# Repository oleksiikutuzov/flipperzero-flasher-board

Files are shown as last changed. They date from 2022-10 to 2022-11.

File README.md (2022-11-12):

# flipperzero-flasher-board

Since version 0.70.1 you can set RTS/DTR pins to pins 16/15 and use only one row of pins for this flasher board.

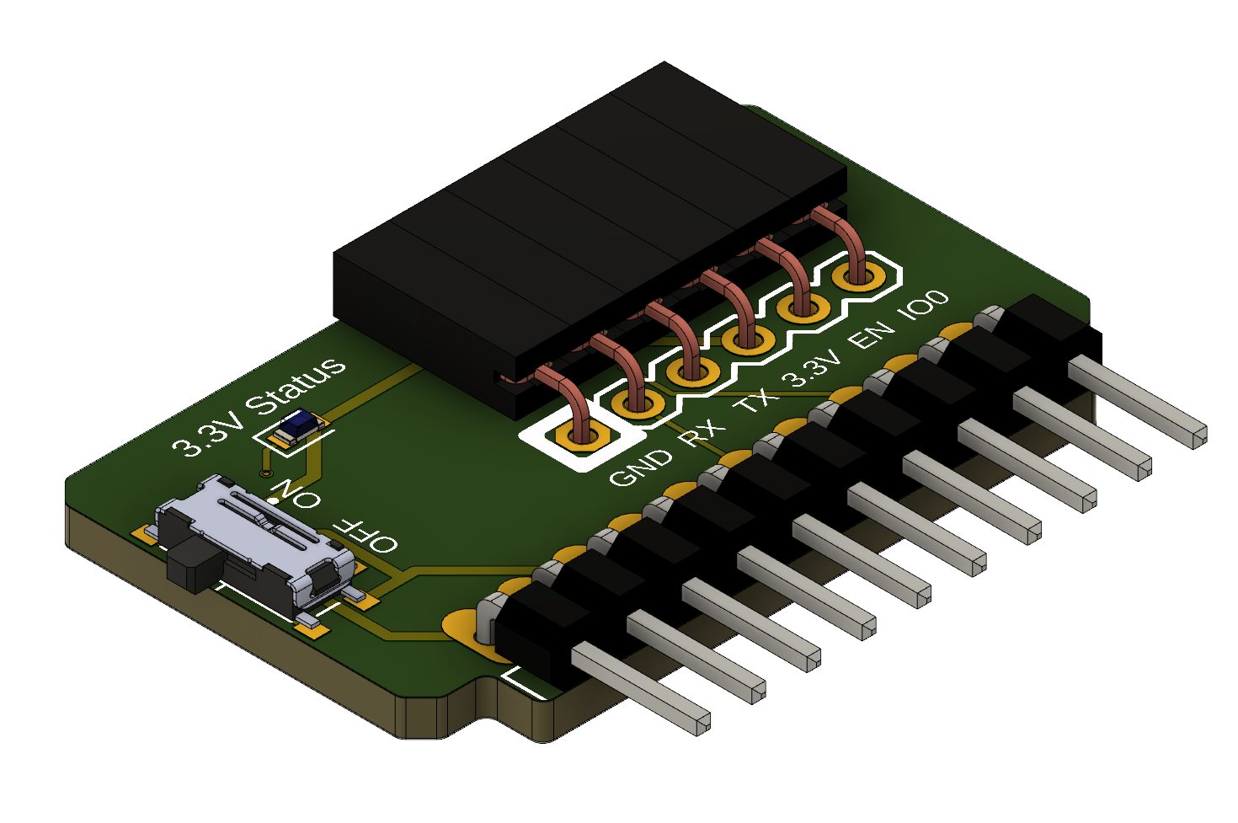
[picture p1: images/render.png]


I made this simple board to flash my ESP32 projects. It uses the [ESPFlash](https://github.com/SuperHouse/ESPFlash) pinout. Flasher has a switch to toggle 3.3V from Flipper Zero if you need to power the device you are flashing from an external power source. Recommended PCB thickness is 1.0 - 1.2 mm.

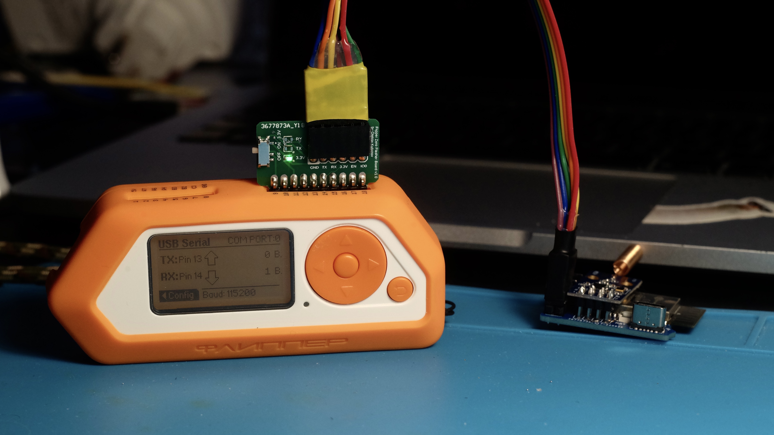
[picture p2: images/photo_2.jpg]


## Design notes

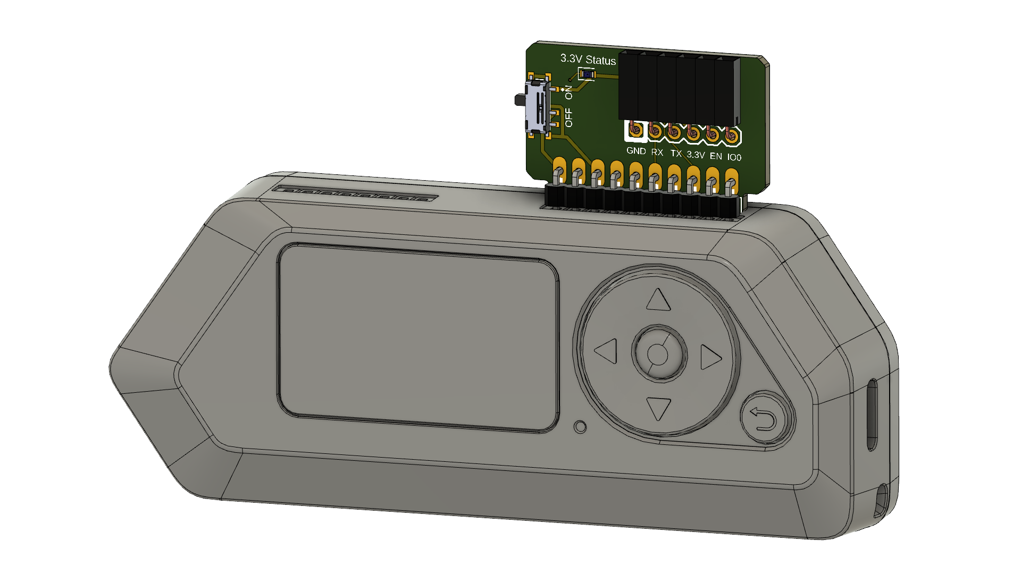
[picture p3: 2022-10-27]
images/render-flipper.png

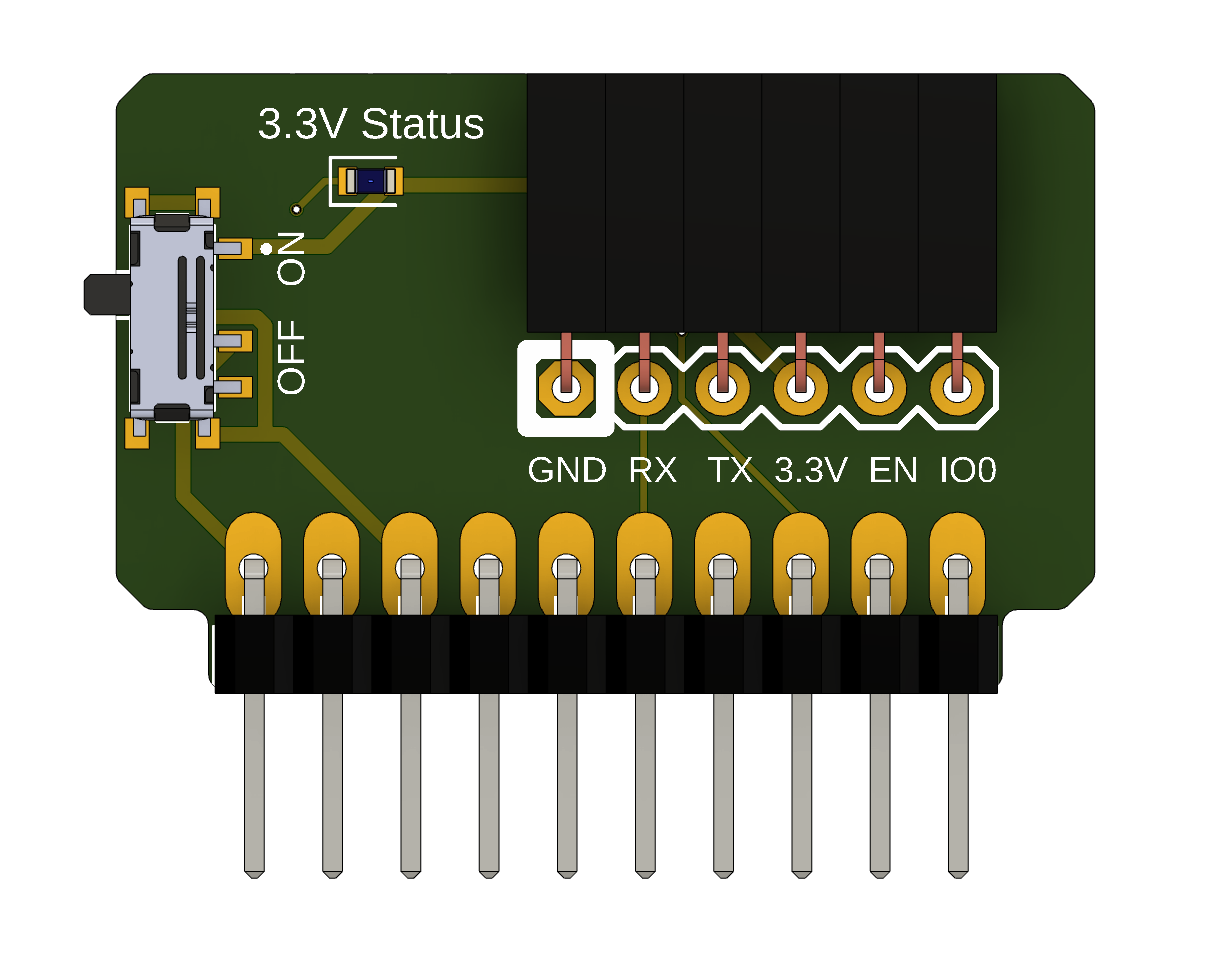
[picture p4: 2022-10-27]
images/TOP v1.1.png

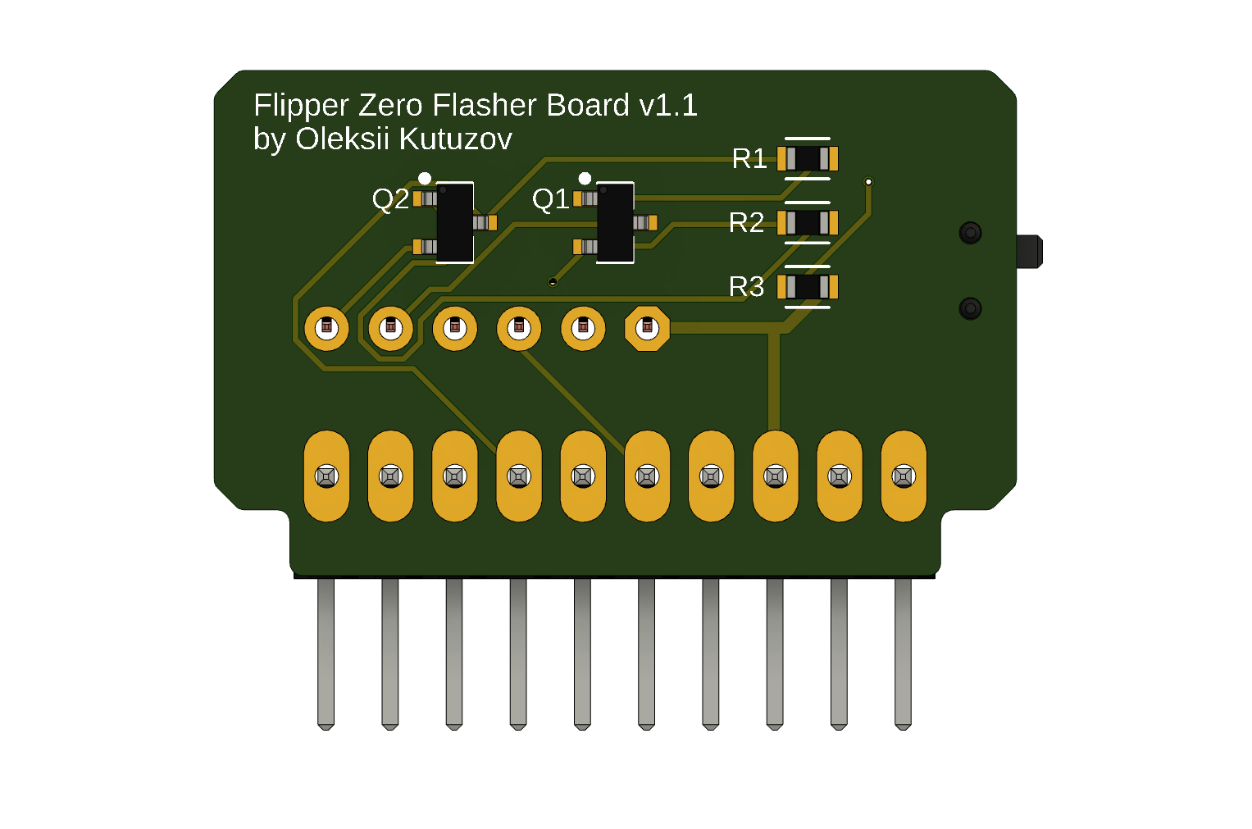
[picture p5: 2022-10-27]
images/BOTTOM v1.1.png

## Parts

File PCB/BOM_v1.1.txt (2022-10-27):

Partlist exported from /var/folders/tq/b2m_bkf11ld61j4hqq2g93cr0000gn/T/Neutron/ElectronFileOutput/14894/sch-362ab598-894d-49ed-90d1-658ffdb2f589/Schematic v7.sch at 27.10.22 18:26

Part Value                   Device                   Package             Description                                              
D1   LED_GREEN               CHIP-FLAT-B_0603-0.55MM  LEDC1608X55N_FLAT-B                                                          
ESPF ESPFLASH-1X6-2.54-PLAIN ESPFLASH-1X6-2.54-PLAIN  1X6-2.54-PLAIN      ESPFlash                                                 
JP1  PINHD-1X10/90           PINHD-1X10/90            1X10/90             PIN HEADER                                               
Q1   NPN                     NPN_SOT23-BEC            SOT95P237X112-3N    NPN - Generic                                            
Q2   NPN                     NPN_SOT23-BEC            SOT95P237X112-3N    NPN - Generic                                            
R1   12K                     R_CHIP-0603(1608-METRIC) RESC1608X60         Resistor Fixed - Generic                                 
R2   12K                     R_CHIP-0603(1608-METRIC) RESC1608X60         Resistor Fixed - Generic                                 
R3   4.7K                    R_CHIP-0603(1608-METRIC) RESC1608X60         Resistor Fixed - Generic                                 
SW1  MLL1200S                MLL1200S                 SW_MLL1200S         Switch Slide SPDT Side Slide 0.3A 4VDC Gull Wing SMD Box 
                                                                          https://a.aliexpress.com/_EyNVWSJ

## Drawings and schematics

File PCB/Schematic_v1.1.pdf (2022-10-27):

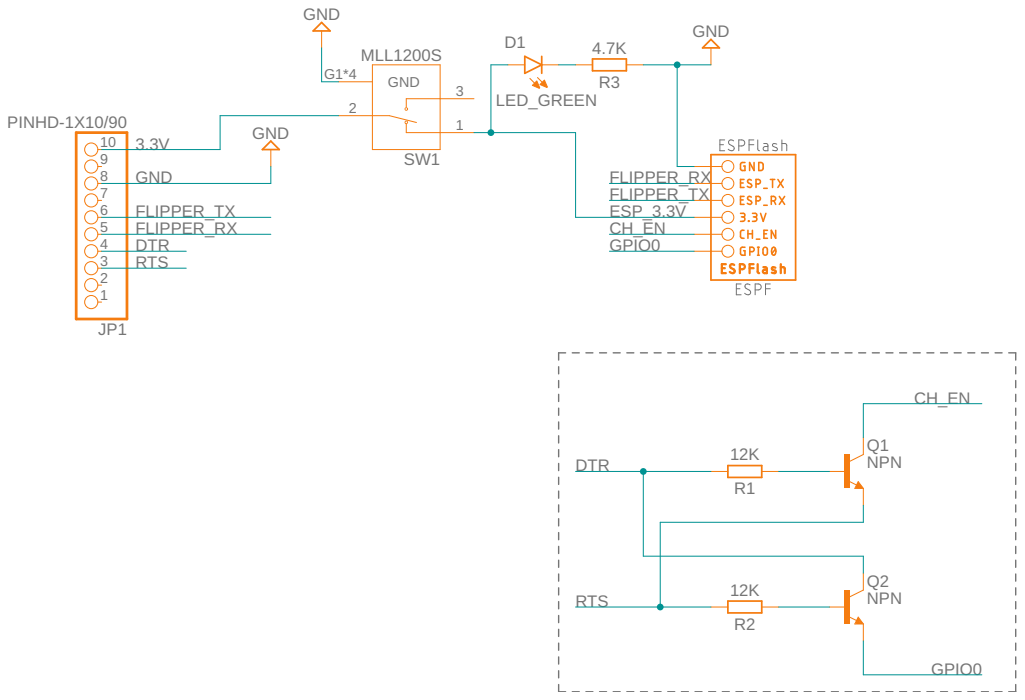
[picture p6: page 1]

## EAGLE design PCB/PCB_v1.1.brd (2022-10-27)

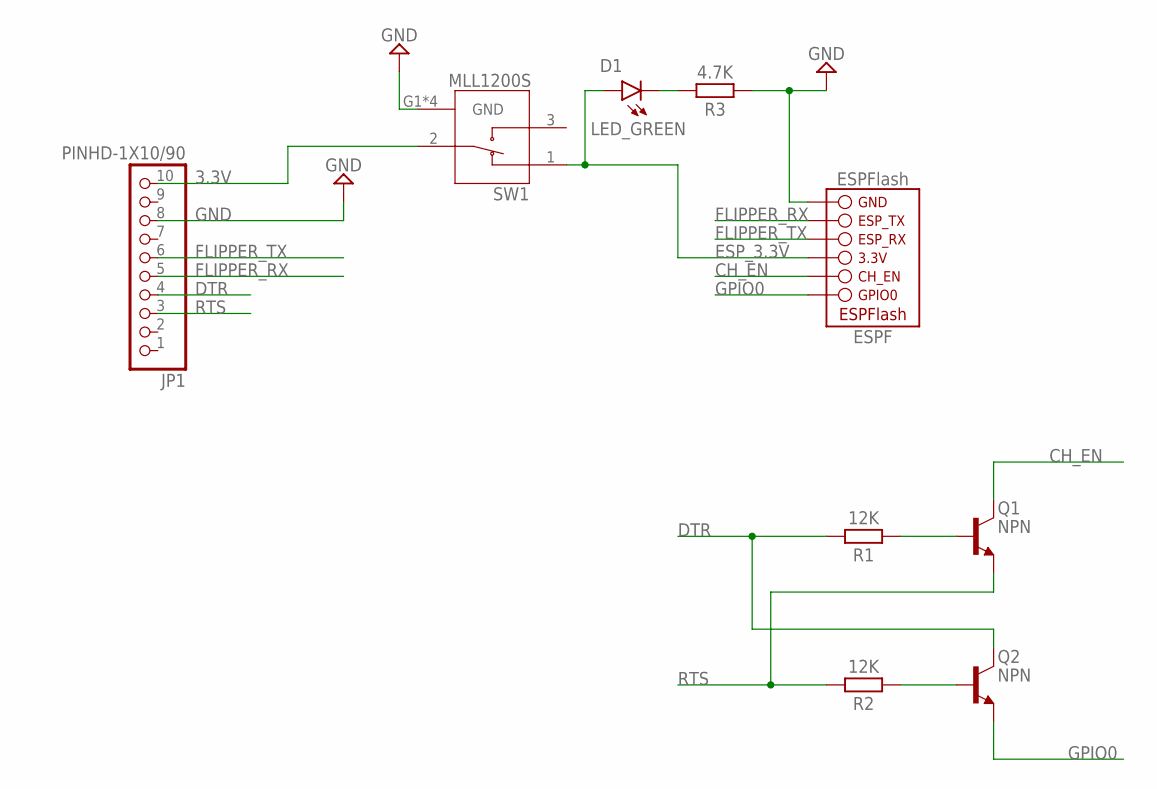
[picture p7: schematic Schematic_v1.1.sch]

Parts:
D1: LED_GREEN; LEDC1608X55N_FLAT-B
ESPF: ESPFLASH-1X6-2.54-PLAIN; 1X6-2.54-PLAIN
JP1: PINHD-1X10/90; 1X10/90
Q1, Q2: NPN; SOT95P237X112-3N
R1, R2: 12K; RESC1608X60
R3: 4.7K; RESC1608X60
SW1: MLL1200S; SW_MLL1200S

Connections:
3.3V: JP1.10, SW1.2
CH_EN: ESPF.5 (CH_EN), Q1.3 (C)
DTR: JP1.4, Q2.3 (C), R1.1
ESP_3.3V: D1.A, ESPF.4 (3.3V), SW1.1
FLIPPER_RX: ESPF.2 (ESP_TX), JP1.5
FLIPPER_TX: ESPF.3 (ESP_RX), JP1.6
GND: ESPF.1 (GND), JP1.8, R3.2, SW1.G1 (GND), SW1.G2 (GND), SW1.G3 (GND), SW1.G4 (GND)
GPIO0: ESPF.6 (GPIO0), Q2.2 (E)
unnamed: D1.C, R3.1
unnamed: Q1.1 (B), R1.2
unnamed: Q2.1 (B), R2.2
RTS: JP1.3, Q1.2 (E), R2.1

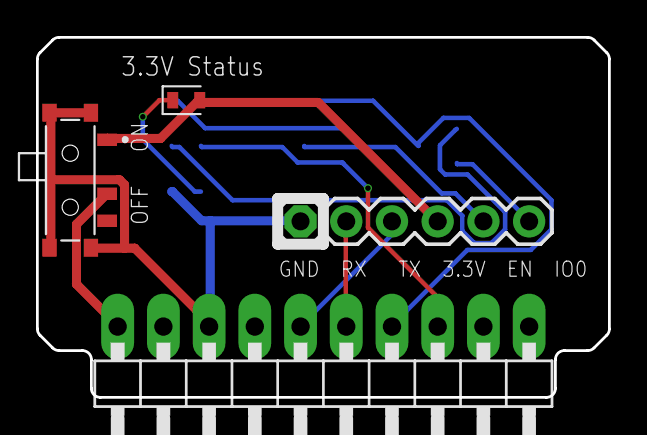
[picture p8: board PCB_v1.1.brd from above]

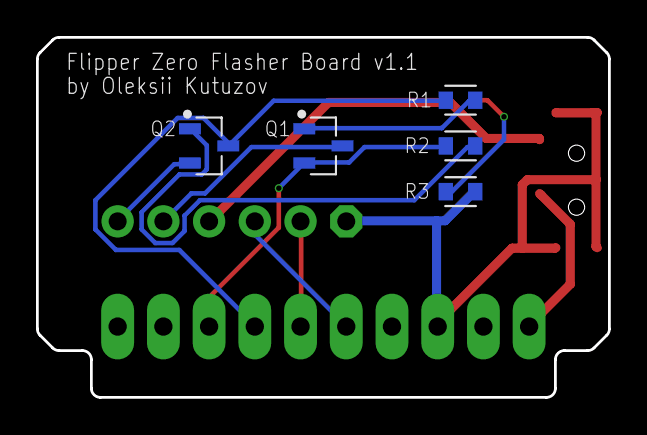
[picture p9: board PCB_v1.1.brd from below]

Board: 2 copper layers, 31.8 x 20.0 mm, 9 parts (5 on the bottom side), 12 nets.

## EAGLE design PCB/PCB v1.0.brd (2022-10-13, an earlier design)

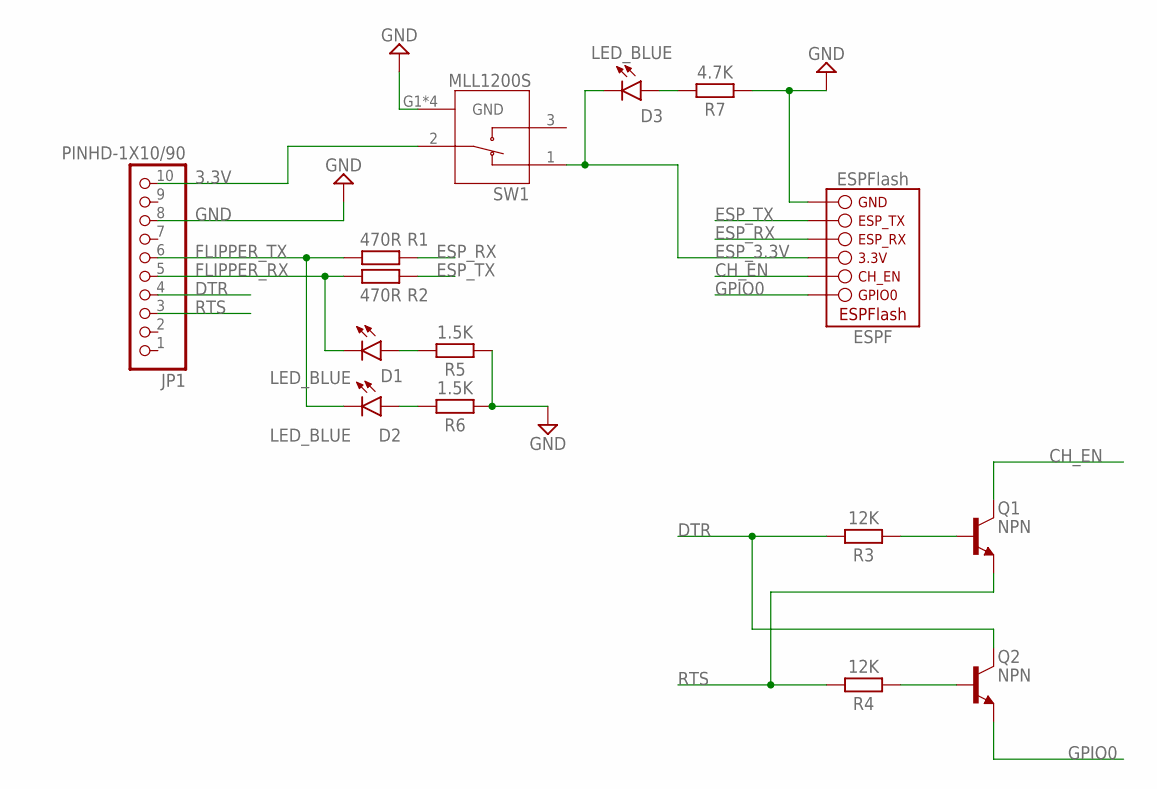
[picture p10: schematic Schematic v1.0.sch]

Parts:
D1, D2, D3: LED_BLUE; LEDC1608X55N_FLAT-B
ESPF: ESPFLASH-1X6-2.54-PLAIN; 1X6-2.54-PLAIN
JP1: PINHD-1X10/90; 1X10/90
Q1, Q2: NPN; SOT95P237X112-3N
R1, R2: 470R; RESC1608X60
R3, R4: 12K; RESC1608X60
R5, R6: 1.5K; RESC1608X60
R7: 4.7K; RESC1608X60
SW1: MLL1200S; SW_MLL1200S

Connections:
3.3V: JP1.10, SW1.2
CH_EN: ESPF.5 (CH_EN), Q1.3 (C)
DTR: JP1.4, Q2.3 (C), R3.1
ESP_3.3V: D3.C, ESPF.4 (3.3V), SW1.1
ESP_RX: ESPF.3 (ESP_RX), R1.2
ESP_TX: ESPF.2 (ESP_TX), R2.2
FLIPPER_RX: D1.C, JP1.5, R2.1
FLIPPER_TX: D2.C, JP1.6, R1.1
GND: ESPF.1 (GND), JP1.8, R5.2, R6.2, R7.2, SW1.G1 (GND), SW1.G2 (GND), SW1.G3 (GND), SW1.G4 (GND)
GPIO0: ESPF.6 (GPIO0), Q2.2 (E)
unnamed: D1.A, R5.1
unnamed: Q1.1 (B), R3.2
unnamed: D2.A, R6.1
unnamed: Q2.1 (B), R4.2
unnamed: D3.A, R7.1
RTS: JP1.3, Q1.2 (E), R4.1

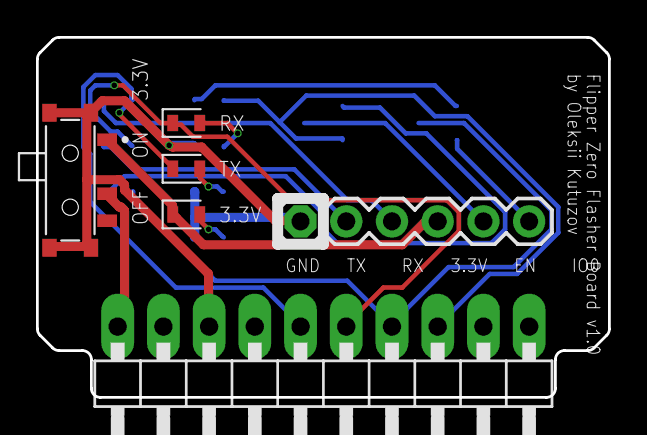
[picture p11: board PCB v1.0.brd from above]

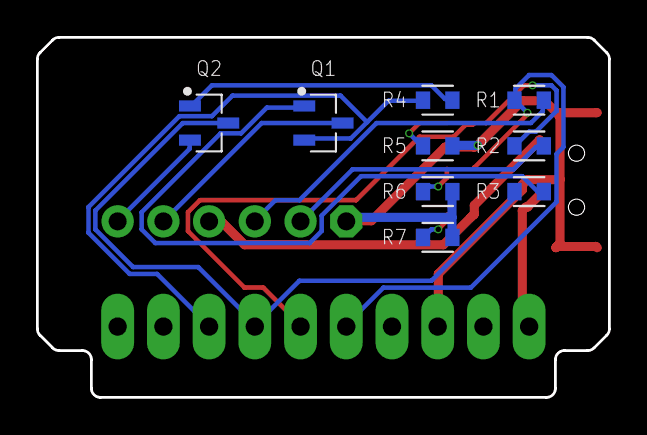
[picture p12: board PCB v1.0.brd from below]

Board: 2 copper layers, 31.8 x 20.0 mm, 15 parts (9 on the bottom side), 16 nets.

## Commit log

2022-10-27 Fix schematic
    [PCB_v1.1.brd, Schematic_v1.1.sch]
2022-10-27 Add suggested PCB thickness
